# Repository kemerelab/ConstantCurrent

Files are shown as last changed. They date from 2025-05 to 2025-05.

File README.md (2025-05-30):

# ConstantCurrent
Circuits for driving constant current stimulators for electrical biphasic pulses and diodes.

### Currently in Prototyping stage

1. 3A LED driver.
2. Constant current biphasic pulses using low power op amps.

### Goals

1. Integrate with https://github.com/kemerelab/pi-stimserver project.

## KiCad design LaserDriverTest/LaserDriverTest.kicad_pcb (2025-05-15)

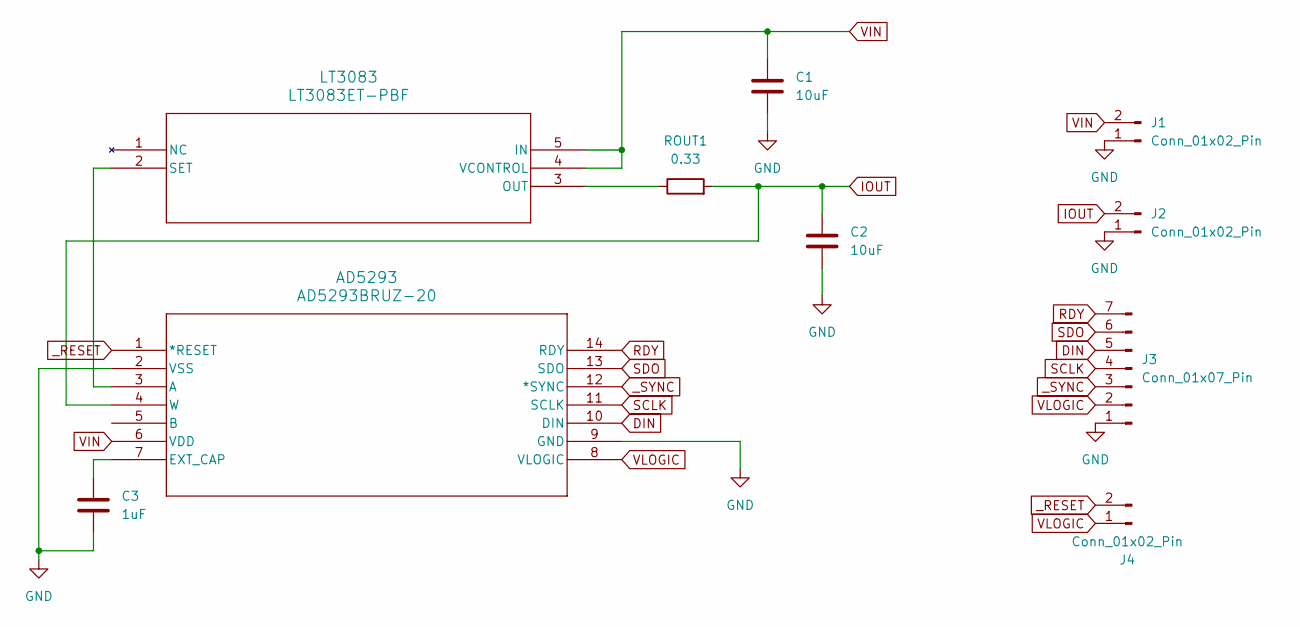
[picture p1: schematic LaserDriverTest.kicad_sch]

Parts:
AD5293: AD5293BRUZ-20; RU_14_ADI
C1, C2: 10uF; C_1206_3216Metric
C3: 1uF; C_1206_3216Metric
J1, J2, J4: Conn_01x02_Pin; PinHeader_1x02_P2.54mm_Vertical
J3: Conn_01x07_Pin; PinHeader_1x07_P2.54mm_Vertical
LT3083: LT3083ET-PBF; TO220-5_T
ROUT1: 0.33; R_4020_10251Metric

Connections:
DIN: AD5293.10 (DIN), J3.5
GND: AD5293.2 (VSS), AD5293.9 (GND), C1.2, C2.2, C3.2, J1.1, J2.1, J3.1
IOUT: AD5293.4 (W), C2.1, J2.2, ROUT1.2
unnamed: AD5293.3 (A), LT3083.2 (SET)
unnamed: AD5293.7 (EXT_CAP), C3.1
unnamed: LT3083.3 (OUT), ROUT1.1
RDY: AD5293.14 (RDY), J3.7
SCLK: AD5293.11 (SCLK), J3.4
SDO: AD5293.13 (SDO), J3.6
VIN: AD5293.6 (VDD), C1.1, J1.2, LT3083.4 (VCONTROL), LT3083.5 (IN)
VLOGIC: AD5293.8 (VLOGIC), J3.2, J4.1
_RESET: AD5293.1 (*RESET), J4.2
_SYNC: AD5293.12 (*SYNC), J3.3

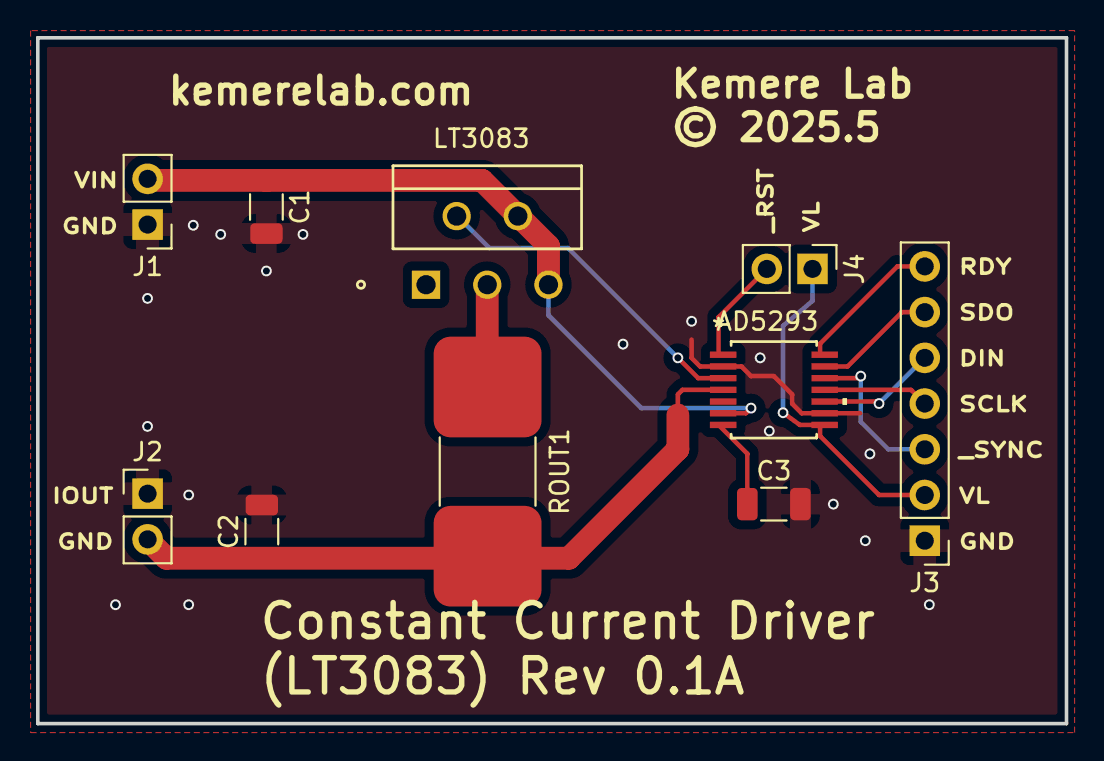
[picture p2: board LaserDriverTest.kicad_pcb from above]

Board: 2 copper layers, 57.1 x 38.1 mm, 10 parts (0 on the bottom side), 13 nets.

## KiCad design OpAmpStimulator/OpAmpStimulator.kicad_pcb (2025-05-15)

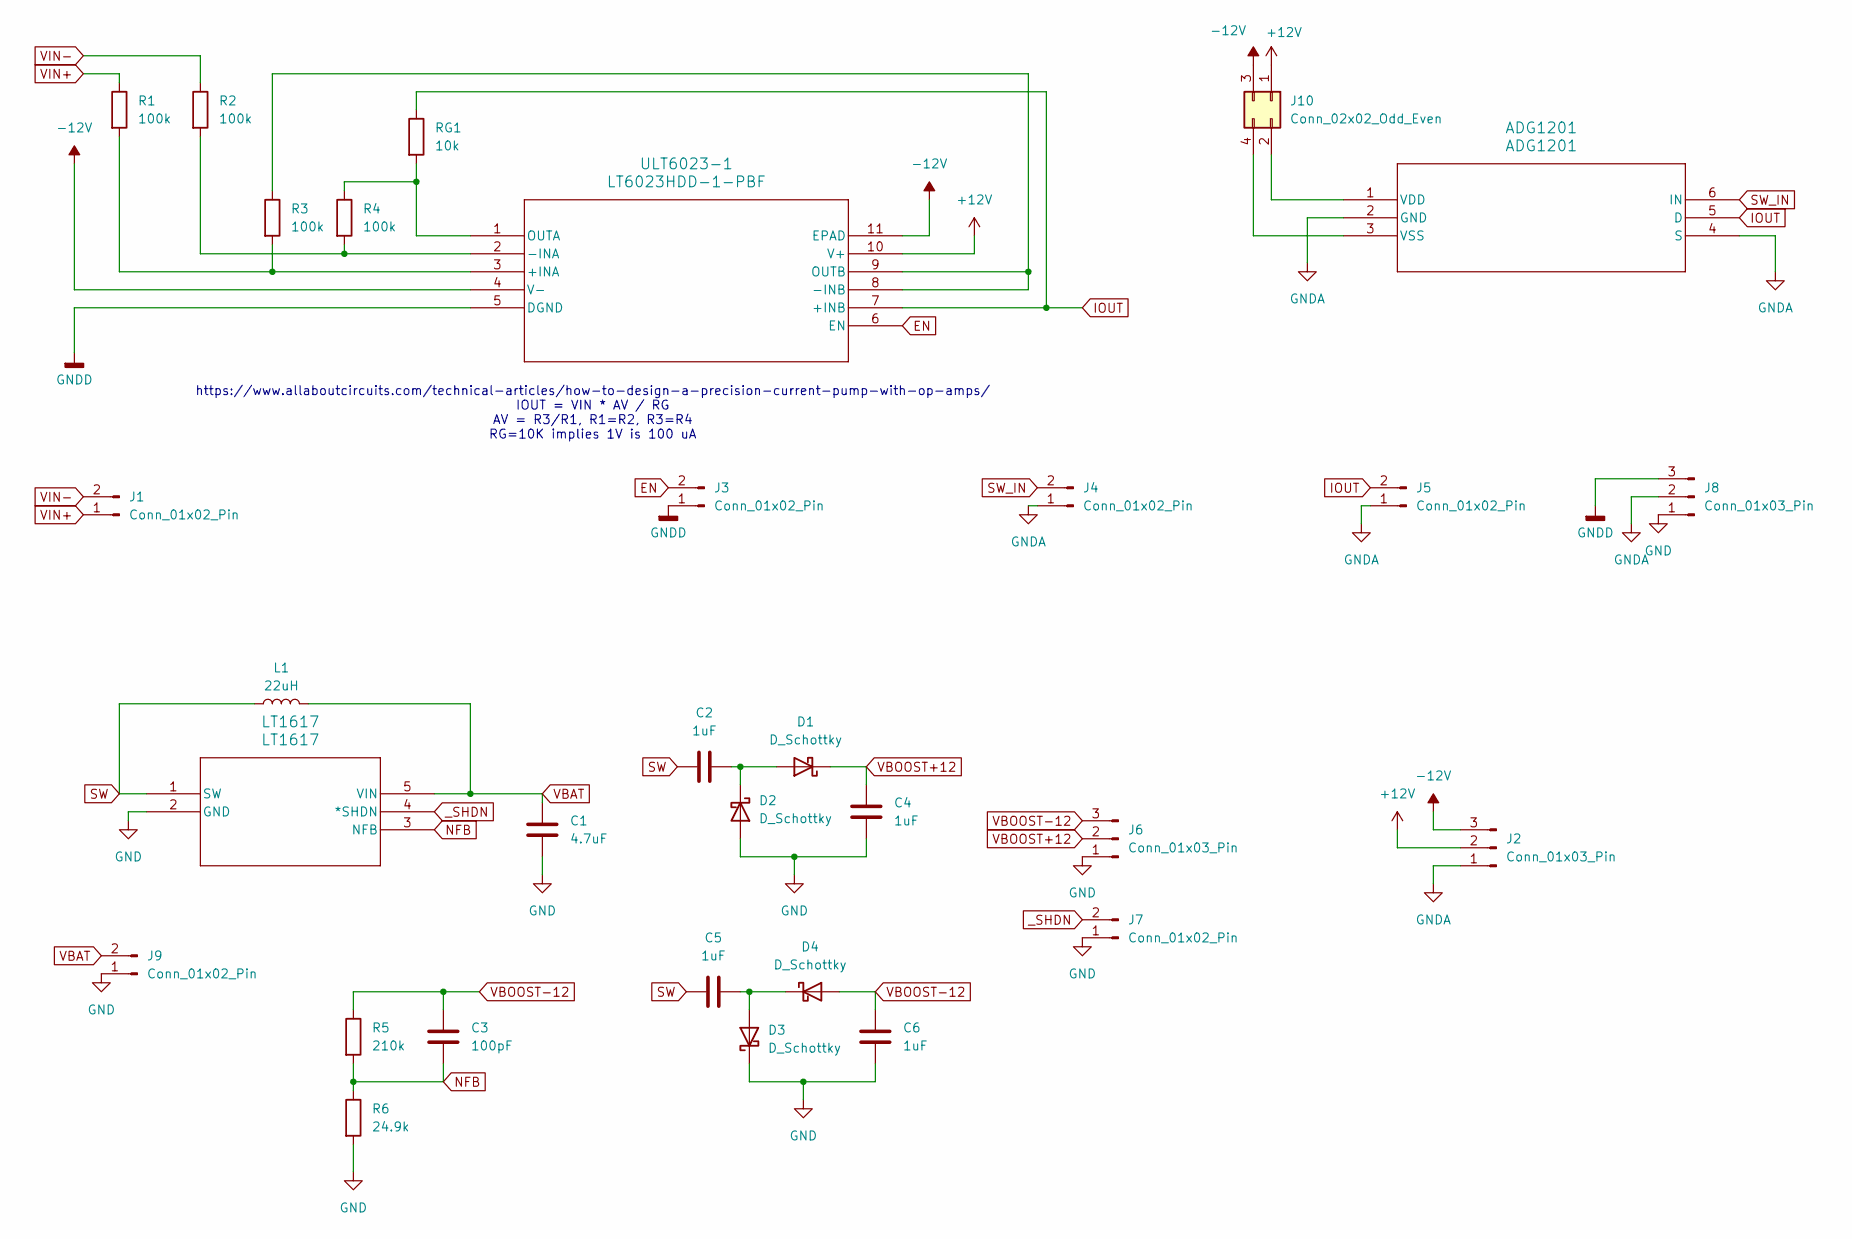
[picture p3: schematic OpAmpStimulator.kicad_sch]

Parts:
ADG1201: ADG1201; RJ_6_ADI
C1: 4.7uF; C_0805_2012Metric
C2, C4, C5, C6: 1uF; C_0603_1608Metric
C3: 100pF; C_0603_1608Metric
D1, D2, D3, D4: D_Schottky; D_0805_2012Metric
J1, J3, J4, J5, J7, J9: Conn_01x02_Pin; PinHeader_1x02_P2.54mm_Vertical
J2, J6, J8: Conn_01x03_Pin; PinHeader_1x03_P2.54mm_Vertical
J10: Conn_02x02_Odd_Even; PinHeader_2x02_P2.54mm_Vertical
L1: 22uH; L_1210_3225Metric
LT1617: LT1617; S_5_ADI
R1, R2, R3, R4: 100k; R_0805_2012Metric
R5: 210k; R_0603_1608Metric
R6: 24.9k; R_0603_1608Metric
RG1: 10k; R_0805_2012Metric
ULT6023-1: LT6023HDD-1-PBF; DFN-10_DD_LIT

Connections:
+12V: J2.2, J10.1, ULT6023-1.10 (V+)
-12V: J2.3, J10.3, ULT6023-1.4 (V-), ULT6023-1.11 (EPAD)
EN: J3.2, ULT6023-1.6 (EN)
GND: C1.1, C4.2, C6.2, D2.2 (A), D3.1 (K), J6.1, J7.1, J8.1, J9.1, LT1617.2 (GND), R6.2
GNDA: ADG1201.2 (GND), ADG1201.4 (S), J2.1, J4.1, J5.1, J8.2
GNDD: J3.1, J8.3, ULT6023-1.5 (DGND)
IOUT: ADG1201.5 (D), J5.2, RG1.1, ULT6023-1.7 (+INB)
NFB: C3.2, LT1617.3 (NFB), R5.2, R6.1
unnamed: ADG1201.1 (VDD), J10.2
unnamed: ADG1201.3 (VSS), J10.4
unnamed: C2.2, D1.2 (A), D2.1 (K)
unnamed: C5.2, D3.2 (A), D4.1 (K)
unnamed: R1.2, R3.2, ULT6023-1.3 (+INA)
unnamed: R2.2, R4.2, ULT6023-1.2 (-INA)
unnamed: R3.1, ULT6023-1.8 (-INB), ULT6023-1.9 (OUTB)
unnamed: R4.1, RG1.2, ULT6023-1.1 (OUTA)
SW: C2.1, C5.1, L1.1, LT1617.1 (SW)
SW_IN: ADG1201.6 (IN), J4.2
VBAT: C1.2, J9.2, L1.2, LT1617.5 (VIN)
VBOOST+12: C4.1, D1.1 (K), J6.2
VBOOST-12: C3.1, C6.1, D4.2 (A), J6.3, R5.1
VIN+: J1.1, R1.1
VIN-: J1.2, R2.1
_SHDN: J7.2, LT1617.4 (*SHDN)

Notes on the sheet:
https://www.allaboutcircuits.com/technical-articles/how-to-design-a-precision-current-pump-with-op-amps/ IOUT = VIN * AV / RG AV = R3/R1, R1=R2, R3=R4 RG=10K implies 1V is 100 uA

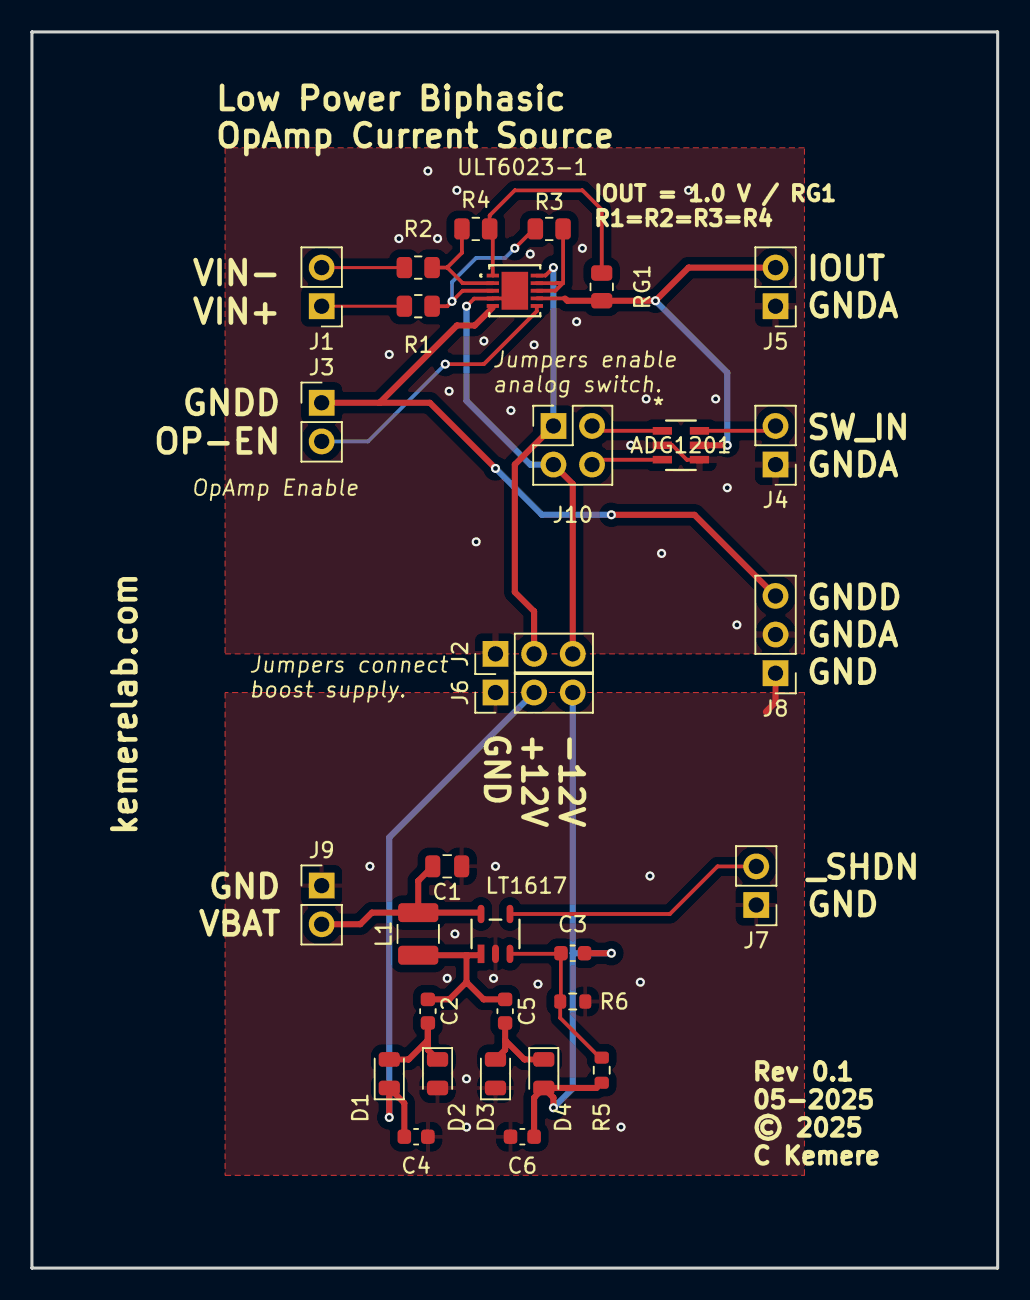
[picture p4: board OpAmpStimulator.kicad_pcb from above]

Board: 2 copper layers, 63.5 x 81.3 mm, 31 parts (0 on the bottom side), 24 nets.

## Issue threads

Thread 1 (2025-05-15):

Add microcontroller controls for output

kemerelab, 2025-05-15:
Needed features to be added for functionality

1. Microcontroller control circuit:
  - LED driver needs SPI to control digital potentiometer
  - Constant current stimulator needs DAC pulses on two pins to drive stimulation, 1 GPIO to drive grounding switch on output, 1 GPIO to drive low power mode of op amp
2. Microcontroller stimulation control protocol:
  - Stimulate using a GPIO pulse from Pi? see https://github.com/kemerelab/pi-stimserver
  - Configure using a UART interface?
  - Alternatively, configure using a firmware upload blob?

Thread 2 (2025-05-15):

Test LED driver circuit

kemerelab, 2025-05-15:
1. Can we create a ramp stimulus using digital potentiometer?
2. How fast can we change?
3. Can we drive a blue laser diode?

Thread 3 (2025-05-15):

Test constant current driver functionality

kemerelab, 2025-05-15:
1. Implement biphasic pulses using microcontroller DAC output
2. Test biphasic pulses with resistor
3. Test biphasic pulses with actual stimulation electrode

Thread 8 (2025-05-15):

Build Raspberry Pi shield PCB

kemerelab, 2025-05-15:
We'd like to fit:
1. Biphasic constant current electrical stimulation circuit
2. LED driver circuit
3. At least 3 BNC outputs - uA stim (identify with a different style connector!), LED driver, sync pulse
4. A button/knob and screen to control using physical interface rather than ethernet. (I like the screen in this part - https://www.adafruit.com/product/3527)

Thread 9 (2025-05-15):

Provide completely isolated power for e-stim

kemerelab, 2025-05-15:
Horrible ground loops happen when doing electrophysiological recordings with a stimulator that shares a ground current with the ephys system. We normally use battery powered isolators. It's worth exploring transformer or optical circuits that might allow us to have plug-in power for the stimulator. Otherwise, we should add a battery (and charging circuit?).

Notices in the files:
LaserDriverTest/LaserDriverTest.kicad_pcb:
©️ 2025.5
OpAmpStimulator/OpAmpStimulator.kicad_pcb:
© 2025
